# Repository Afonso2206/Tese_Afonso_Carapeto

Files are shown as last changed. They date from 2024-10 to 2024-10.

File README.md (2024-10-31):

This repository contains the source code, schematic, and PCB layout for the electronic badge developed as part of the thesis project of Afonso Carapeto. 

Getting Started: Reprogramming the E-Badge:

- Install the Arduino IDE: If you haven't already, download and install the Arduino IDE, which is available at https://www.arduino.cc/en/software.

Add Raspberry Pi Pico Support: In the Arduino IDE, you’ll need to add support for the Raspberry Pi Pico board (the microcontroller used in this badge). Follow these steps:
- Open the Arduino IDE and go to File > Preferences.
- In the "Additional Boards Manager URLs" field, add the following URL: https://github.com/earlephilhower/arduino-pico/releases/download/global/package_rp2040_index.json

Install the Raspberry Pi Pico Package:

- Go to Tools > Board > Boards Manager.
- Search for "Raspberry Pi Pico" in the Boards Manager.
- Install the package named Raspberry Pi Pico/RP2040 by Earle Philhower.

Select the Board and Port:

- Connect your badge (Raspberry Pi Pico) to your computer via USB.
- In the Arduino IDE, go to Tools > Board and select Raspberry Pi Pico.
- Then, under Tools > Port, select the port that corresponds to your badge.

  Upload Code to the Badge: Now you can open any of the .ino files in this repository, modify the code if desired, and click Upload to program the badge.

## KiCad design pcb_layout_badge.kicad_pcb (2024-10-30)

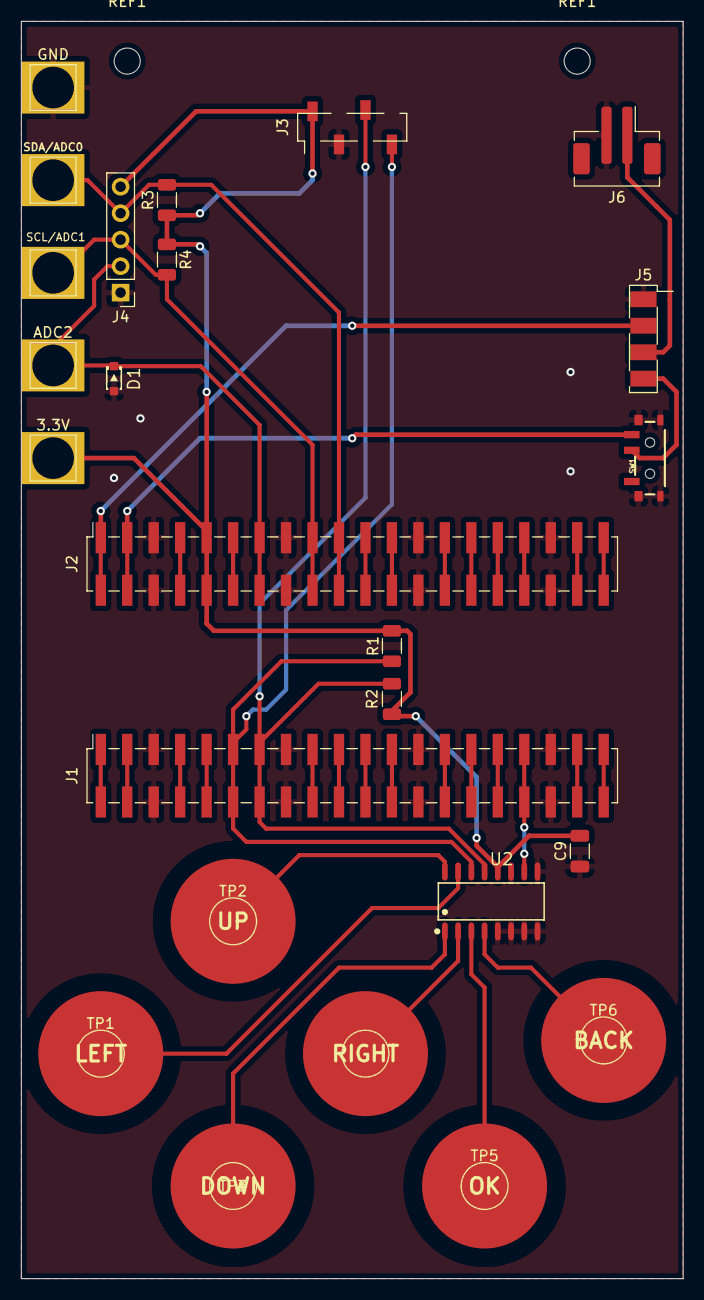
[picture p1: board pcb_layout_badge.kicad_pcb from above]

Board: 2 copper layers, 63.5 x 120.7 mm, 28 parts (1 on the bottom side), 41 nets.

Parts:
3.3V: TestPoint; TestPoint_THTPad_4.0x4.0mm_Drill2.0mm
ADC2: TestPoint; TestPoint_THTPad_4.0x4.0mm_Drill2.0mm
C9: 0.1u; C_1206_3216Metric
D1: D_Zener; zener
G1: LOGO
GND: TestPoint; TestPoint_THTPad_4.0x4.0mm_Drill2.0mm
J1, J2: Conn_01x40_Female; PinSocket_2x20_P2.54mm_Vertical_SMD
J3: Conn_01x04_Female; PinSocket_1x04_P2.54mm_Vertical_SMD_Pin1Left
J4: Conn_01x05_Male; PinHeader_1x05_P2.54mm_Vertical
J5: Conn_01x04_Male; carregador_v2
J6: Conn_01x02_Male; JST_PH_B2B-PH-SM4-TB_1x02-1MP_P2.00mm_Vertical
R1, R2, R3, R4: 4.7k; R_1206_3216Metric
REF1, REF1#2: MountingHole_2.5mm
SCL/ADC1: TestPoint; TestPoint_THTPad_4.0x4.0mm_Drill2.0mm
SDA/ADC0: TestPoint; TestPoint_THTPad_4.0x4.0mm_Drill2.0mm
SW1: SW_SPST; SWITCH_SPST_SMD_A
TP1, TP2, TP3, TP4, TP5, TP6: TestPoint; TestPoint_Pad_D4.0mm
U2: cap_sensor; SOP-16_L10.0-W3.9-P1.27-LS6.0-BL

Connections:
+3.3V: 3.3V.1, C9.2, J2.9, J2.10, J3.1, J4.5, R1.2, R2.2, R3.1, R4.1, U2.12 (VDD)
ADC0/SDA1: J2.19, J2.20, J4.4, R3.2, SDA/ADC0.1
ADC1/SCL1: J2.17, J2.18, J4.3, R4.2, SCL/ADC1.1
ADC2: ADC2.1, D1.1 (K), J2.13, J2.14, J4.2
GND: C9.1, D1.2 (A), GND.1, J1.5, J1.6, J1.15, J1.16, J1.25, J1.26, J1.35, J1.36, J2.5, J2.6, J2.15, J2.16, J2.25, J2.26, J2.35, J2.36, J3.2, J4.1, J5.1, J6.2, SW1.GND1, SW1.GND2, SW1.GND3, SW1.GND4, U2.5 (Key7), U2.6 (Key8), U2.7 (Key9), U2.8 (Key10), U2.9 (Key11), U2.11 (VSS)
unnamed: J1.1, J1.2
unnamed: J1.3, J1.4
unnamed: J1.7, J1.8
unnamed: J1.9, J1.10
unnamed: J1.17, J1.18
unnamed: J1.19, J1.20
unnamed: J1.21, J1.22
unnamed: J1.23, J1.24
unnamed: J1.27, J1.28
unnamed: J1.29, J1.30
unnamed: J1.31, J1.32
unnamed: J1.33, J1.34, U2.10 (Key12/IRQ)
unnamed: J1.37, J1.38
unnamed: J1.39, J1.40
unnamed: J2.7, J2.8
unnamed: J2.11, J2.12
unnamed: J2.21, J2.22
unnamed: J2.23, J2.24
unnamed: J2.27, J2.28
unnamed: J2.29, J2.30
unnamed: J2.31, J2.32
unnamed: J2.33, J2.34
unnamed: J2.37, J2.38
unnamed: J2.39, J2.40
unnamed: J5.4, SW1.2 (B)
unnamed: TP1.1, U2.15 (KEY1)
unnamed: TP2.1, U2.16 (KEY2)
unnamed: TP3.1, U2.1 (KEY3)
unnamed: TP4.1, U2.2 (Key4)
unnamed: TP5.1, U2.3 (Key5)
unnamed: TP6.1, U2.4 (Key6)
SCL0: J1.13, J1.14, J3.3, R2.1, U2.13 (SCL)
SDA0: J1.11, J1.12, J3.4, R1.1, U2.14 (SDA)
VBAT: J5.3, J6.1
VBUS: J2.1, J2.2, J5.2
VSYS: J2.3, J2.4, SW1.1 (A)

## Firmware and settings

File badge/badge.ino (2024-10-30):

#include "oled.h"

#include "snake.h"

#include "time_functions.h"

#include "treasure_hunt.h"

#include "tic_tac_toe.h"

#include <Wire.h>

#define SLAVE_ADDRESS 0x50 //   Touch Key Controller Address

GyverOLED<SSH1106_128x64> oled;

//----------------------------------------TIMEOUT VARIABLES---------------------------------//

unsigned long lastActivityTime = 0;
const unsigned long inactivityTimeout = 10000;

//--------------------------------TOUCH KEY CONTROLLER VARIABLES-----------------------------//
uint8_t KeyStatus0, i; 
uint8_t Array_SettingRegisters[22];
bool back_key_pressed = false;

//---------------------------------------SNAKE GAME VARIABLES----------------------------------------//

bool Snake_Game = false;
int xdir = 1;             //player direction
int ydir = 0;

//---------------------------------------TIC TAC TOE VARIABLES----------------------------------------//

bool tic_tac_toe_game = false;

//---------------------------------------TIC TAC TOE VARIABLES----------------------------------------//

bool treasure_hunt = false;

//--------------------------------------------------------------------------------------------------//
//--------------------------------------------------------------------------------------------------//
//--------------------------------------------------------------------------------------------------//

void ReadAndProcessKeyStatus();
void Key_Instrucion(uint8_t KeyPressed);
uint8_t Read_SettingRegisters(uint8_t Register);
void Write_SettingRegisters();

void navigate_up();
void navigate_down();
void exit_submenu();
void select_submenu_option();
void update_menu();
void select_submenu_option();

int main() {

    clock_and_rtc_initialization();    
     

    //I2c Communication Intialization
    Wire.begin();

    //OLED Intialization
    DisplayStartupSequence(); 
    oled.clear();
    update_menu();
    
    //Touch Controller Intialization
    for (i = 0xB0; i < 0xC6; i++) {
        Array_SettingRegisters[i - 0xB0] = Read_SettingRegisters(i);
    }

    Write_SettingRegisters();

    //Main Loop
    while (true) {
        unsigned long currentTime = millis();         //Checks to see if 10 seconds pass without a key being pressed
        if (KeyStatus0 != 0){
          lastActivityTime = currentTime;
        }
        if (currentTime - lastActivityTime >= inactivityTimeout){
          prepareSleep();             //If 10 seconds pass, the pico goes to sleep
        }
        delay(100); 
        ReadAndProcessKeyStatus();
    }
}

//--------------------------------------------------------------------------------------------------//
//--------------------------------------------------------------------------------------------------//
//--------------------------------------------------------------------------------------------------//

void ReadAndProcessKeyStatus() {
    Wire.beginTransmission(SLAVE_ADDRESS);
    Wire.write(0x08); // Key1-8 Status Data Register: 08H (This touch controller supports 12 keys)
    Wire.endTransmission();
    Wire.requestFrom(SLAVE_ADDRESS, 1);
    while (Wire.available()) KeyStatus0 = Wire.read();

    if (KeyStatus0 != 0) {
        //digitalWrite(LED_BUILTIN, HIGH);
        Key_Instruction(KeyStatus0);
    } else {
        //digitalWrite(LED_BUILTIN, LOW);
    }
}

void Key_Instruction(uint8_t KeyPressed) {
  oled.clear();
  oled.home();

  if(!Snake_Game && !tic_tac_toe_game && !treasure_hunt){               //Menu Navigation
    switch (KeyPressed) {
      case 0x01:
        //oled.println("LEFT");    //Presses "LEFT"
        break;
      case 0x02:                 //Presses "UP"
        navigate_up();
        break;
      case 0x04:                 //Presses "DOWN"
        navigate_down();
        break;
      case 0x08:
        //oled.println("RIGHT");   //Presses "RIGHT"
        break;
      case 0x10:                 //Presses "OK"
        if (!in_submenu) {
          in_submenu = true;
          update_menu();
        } else {
          select_submenu_option();    
        }
        break;
      case 0x20:                 //Presses "BACK"
        if (in_submenu) {
          exit_submenu();
          current_submenu_index = 0;
          back_key_pressed = true;
        }
        break;
    }
  }
  else 
  {
    if (KeyStatus0 & 0x20){   //If In Snake Game
      exit_submenu();
      back_key_pressed = true;
      oled.update();
    }
  }
  
  //oled.update();
}


uint8_t Read_SettingRegisters(uint8_t Register) {
    Wire.beginTransmission(SLAVE_ADDRESS);
    Wire.write(Register);
    Wire.endTransmission();
    Wire.requestFrom(SLAVE_ADDRESS, 1);
    while (Wire.available()) return Wire.read();
    return 0;
}

void Write_SettingRegisters() {
    Wire.beginTransmission(SLAVE_ADDRESS);
    Wire.write(0xB0);
    for (i = 0; i < 22; i++) {
        Wire.write(Array_SettingRegisters[i]);
    }
    Wire.endTransmission();
}

void navigate_up() {
  // Move selection up based on whether in main menu or submenu
  if (in_submenu) {
    // Move selection up in the submenu
    if (current_submenu_index > 0) {
      current_submenu_index--;
    } else {
      // Wrap around to the bottom of the submenu if at the top
      current_submenu_index = submenu_length - 1;
    }
  } else {
    // Move selection up in the main menu
    if (current_index > 0) {
      current_index--;
    } else {
      // Wrap around to the bottom of the menu if at the top
      current_index = menu_length - 1;
    }
  }
  update_menu();
}

void navigate_down() {
  // Move selection down based on whether in main menu or submenu
  if (in_submenu) {
    // Move selection down in the submenu
    if (current_submenu_index < submenu_length - 1) {
      current_submenu_index++;
    } else {
      // Wrap around to the bottom of the submenu if at the top
      current_submenu_index = 0;
    }
  } else {
    // Move selection down in the main menu
    if (current_index < menu_length - 1) {
      current_index++;
    } else {
      // Wrap around to the top of the menu if at the bottom
      current_index = 0;
    }
  }
  update_menu();
}

void exit_submenu() {
  // Exit the submenu and go back to the main menu
  in_submenu = false;
  update_menu();
}

void select_submenu_option() {
  const char* option = submenu_items[current_index][current_submenu_index];
  oled.clear();
  oled.home();
  oled.setScale(1);
  oled.invertText(false);
  if (option == "See student data"){
    print_student_data();                 //Show Student Data
  }
  else if (option == "Show QR Code"){
    displayQRCode(Student_Info);          //Display QR Code with Student Data
  }
  else if (option == "Snake"){
    Snake_Game = true;
    run_snake_game();
  }
  else if (option == "Tic Tac Toe"){
    tic_tac_toe_game = true;
    run_tic_tac_toe();
  }
  else if (option == "Digital"){
    delay(100);
    back_key_pressed = false;
    while(!back_key_pressed){
     digital_Voltmeter();       //Digital Voltmeter
     ReadAndProcessKeyStatus();
     delay(10);
    }
    back_key_pressed = false;
  }
  else if (option == "Analog"){
    delay(100);
    back_key_pressed = false;
    while(!back_key_pressed){     
      analog_Voltmeter();       //Analog Voltmeter
      ReadAndProcessKeyStatus();
      delay(10);
    }
    back_key_pressed = false;
  }
  else if (option == "Treasure Hunt"){    //Treasure Hunt Game
    treasure_hunt = true;
    run_treasure_hunt();
    unsigned long currentTime = millis(); 
    lastActivityTime = currentTime;
  }
  
  else if (option == "Focus Attention"){
    Focus_Preparation();                  //Prints information before starting the Focus Attention Functionality
    back_key_pressed = false;
    while(!back_key_pressed){
      Focus_Attention();                  //Fills the Focus Attention bar
      ReadAndProcessKeyStatus();
      delay(10);
    }
    percent = 0;                          //Puts the percentage of the Focus Attention bar back at zero
    back_key_pressed = false;
  }
  else if (option == "IST Alameda"){
    print_alameda_info();                 //Prints Information about the Alameda Campus
  }
  else if (option == "IST Taguspark"){
    print_taguspark_info();               //Prints Information about the Taguspark Campus
  }
  
  oled.update();
}

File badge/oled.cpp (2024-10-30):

#include "oled.h"

const char* menu_items[6] = {
    "Student Data",
    "Games",
    "Voltmeter",
    "Treasure Hunt",
    "Focus Attention",
    "IST Info"
  };

const char* submenu_items[6][3] = {
  {"See student data", "Show QR Code", nullptr},      // Submenu options for Student Data
  {"Snake", "Tic Tac Toe", nullptr},            // Submenu options for Games
  {"Digital", "Analog", nullptr},    // Submenu options for Voltmeter
  {"Treasure Hunt", nullptr},  // Submenu options for I2C Explorer
  {"Focus Attention", nullptr},  // Submenu options for Focus Attention
  {"IST Alameda", "IST Taguspark", nullptr}       // Submenu options for IST Info
};
  
const int menu_length = sizeof(menu_items) / sizeof(menu_items[0]);
int current_index = 0;
int current_submenu_index = 0;
bool in_submenu = false;
int submenu_length = 0;

const char* Student_Info = "BEGIN:VCARD\n"
                       "VERSION:3.0\n"
                       "FN;CHARSET=UTF-8:Afonso Santos Carapeto\n"
                       "N;CHARSET=UTF-8:Carapeto;Afonso;Santos;;\n"
                       "EMAIL;CHARSET=UTF-8;type=HOME,INTERNET:afonso.carapeto@tecnico.ulisboa.pt\n"
                       "TEL;TYPE=CELL:+351 929264325\n"
                       "NOTE;CHARSET=UTF-8:MEEC nº 93763\n"
                       "REV:2024-01-16T14:41:13.993Z\n"
                       "END:VCARD\n"; 

byte percent = 0;
//-------------------------------------------------------------------------------------------------------------------//

void DisplayStartupSequence() {

    const uint8_t IST_Logo[128*8] PROGMEM  = {
  0x00, 0x00, 0x00, 0x00, 0x00, 0x00, 0x00, 0x00, 0x00, 0x00, 0x00, 0x00, 0x00, 0x00, 0x00, 0x00, 
  0x00, 0x00, 0x00, 0x00, 0x00, 0x00, 0x00, 0x00, 0x00, 0x00, 0x00, 0x00, 0x00, 0x00, 0x00, 0x00, 
  0x00, 0x00, 0x00, 0x00, 0x00, 0x00, 0xff, 0xff, 0xff, 0xff, 0xff, 0xff, 0xff, 0xff, 0xff, 0xff, 
  0xff, 0xff, 0xff, 0xff, 0xff, 0xff, 0xff, 0xff, 0xff, 0xff, 0xff, 0xff, 0xff, 0xff, 0xff, 0xff, 
  0x7f, 0x3f, 0x3f, 0xbf, 0xbf, 0xbf, 0xbf, 0x3f, 0x3f, 0x3f, 0x7f, 0xff, 0xff, 0xff, 0xff, 0xff, 
  0xff, 0xff, 0xff, 0xff, 0xff, 0xff, 0xff, 0xff, 0xff, 0xff, 0x00, 0x00, 0x00, 0x00, 0x00, 0x00, 
  0x00, 0x00, 0x00, 0x00, 0x00, 0x00, 0x00, 0x00, 0x00, 0x00, 0x00, 0x00, 0x00, 0x00, 0x00, 0x00, 
  0x00, 0x00, 0x00, 0x00, 0x00, 0x00, 0x00, 0x00, 0x00, 0x00, 0x00, 0x00, 0x00, 0x00, 0x00, 0x00, 
  0x00, 0x00, 0x00, 0x00, 0x00, 0x00, 0x00, 0x00, 0x00, 0x00, 0x00, 0x00, 0x00, 0x00, 0x00, 0x00, 
  0x00, 0x00, 0x00, 0x00, 0x00, 0x00, 0x00, 0x00, 0x00, 0x00, 0x00, 0x00, 0x00, 0x00, 0x00, 0x00, 
  0x00, 0x00, 0x00, 0x00, 0x00, 0x00, 0xff, 0xff, 0xff, 0xff, 0xff, 0xff, 0xff, 0xff, 0xff, 0xff, 
  0xff, 0xff, 0xff, 0xff, 0xff, 0xff, 0xff, 0xff, 0xff, 0xff, 0xff, 0xff, 0xff, 0xff, 0x01, 0x00, 
  0x00, 0x00, 0x00, 0xff, 0xff, 0xff, 0xff, 0xf8, 0xe0, 0xe0, 0xe0, 0xe0, 0xff, 0xff, 0xff, 0xff, 
  0xff, 0xff, 0xff, 0xff, 0xff, 0xff, 0xff, 0xff, 0xff, 0xff, 0x00, 0x00, 0x00, 0x00, 0x00, 0x00, 
  0x00, 0x00, 0x00, 0x00, 0x00, 0x00, 0x00, 0x00, 0x00, 0x00, 0x00, 0x00, 0x00, 0x00, 0x00, 0x00, 
  0x00, 0x00, 0x00, 0x00, 0x00, 0x00, 0x00, 0x00, 0x00, 0x00, 0x00, 0x00, 0x00, 0x00, 0x00, 0x00, 
  0x00, 0x00, 0x00, 0x00, 0x00, 0x00, 0x00, 0x00, 0x00, 0x00, 0x00, 0x00, 0x00, 0x00, 0x00, 0x00, 
  0x00, 0x00, 0x00, 0x00, 0x00, 0x00, 0x00, 0x00, 0x00, 0x00, 0x00, 0x00, 0x00, 0x00, 0x00, 0x00, 
  0x00, 0x00, 0x00, 0x00, 0x00, 0x00, 0xff, 0xff, 0xff, 0xff, 0xff, 0xff, 0xff, 0xff, 0xff, 0xff, 
  0xff, 0xff, 0xff, 0xff, 0x01, 0x01, 0x01, 0x01, 0x01, 0xff, 0xff, 0xff, 0xff, 0xff, 0x00, 0x00, 
  0x00, 0x00, 0x00, 0xff, 0xff, 0xf1, 0xf1, 0x01, 0x01, 0x01, 0x01, 0x01, 0xf1, 0xf1, 0xf1, 0xff, 
  0xff, 0xff, 0xff, 0xff, 0xff, 0xff, 0xff, 0xff, 0xff, 0xff, 0x00, 0x00, 0x00, 0x00, 0x00, 0x00, 
  0x00, 0x00, 0x00, 0x00, 0x00, 0x00, 0x00, 0x00, 0x00, 0x00, 0x00, 0x00, 0x00, 0x00, 0x00, 0x00, 
  0x00, 0x00, 0x00, 0x00, 0x00, 0x00, 0x00, 0x00, 0x00, 0x00, 0x00, 0x00, 0x00, 0x00, 0x00, 0x00, 
  0x00, 0x00, 0x00, 0x00, 0x00, 0x00, 0x00, 0x00, 0x00, 0x00, 0x00, 0x00, 0x00, 0x00, 0x00, 0x00, 
  0x00, 0x00, 0x00, 0x00, 0x00, 0x00, 0x00, 0x00, 0x00, 0x00, 0x00, 0x00, 0x00, 0x00, 0x00, 0x00, 
  0x00, 0x00, 0x00, 0x00, 0x00, 0x00, 0xff, 0xff, 0xff, 0xff, 0xff, 0xff, 0xff, 0xff, 0xff, 0xff, 
  0xff, 0xff, 0xff, 0xff, 0x00, 0x00, 0x00, 0x00, 0x00, 0xff, 0xff, 0xff, 0xff, 0xff, 0x00, 0x00, 
  0x00, 0x00, 0x00, 0xff, 0xff, 0xff, 0xff, 0x00, 0x00, 0x00, 0x00, 0x00, 0xff, 0xff, 0xff, 0xff, 
  0xff, 0xff, 0xff, 0xff, 0xff, 0xff, 0xff, 0xff, 0xff, 0xff, 0x00, 0x00, 0x00, 0x00, 0x00, 0x00, 
  0x00, 0x00, 0x00, 0x00, 0x00, 0x00, 0x00, 0x00, 0x00, 0x00, 0x00, 0x00, 0x00, 0x00, 0x00, 0x00, 
  0x00, 0x00, 0x00, 0x00, 0x00, 0x00, 0x00, 0x00, 0x00, 0x00, 0x00, 0x00, 0x00, 0x00, 0x00, 0x00, 
  0x00, 0x00, 0x00, 0x00, 0x00, 0x00, 0x00, 0x00, 0x00, 0x00, 0x00, 0x00, 0x00, 0x00, 0x00, 0x00, 
  0x00, 0x00, 0x00, 0x00, 0x00, 0x00, 0x00, 0x00, 0x00, 0x00, 0x00, 0x00, 0x00, 0x00, 0x00, 0x00, 
  0x00, 0x00, 0x00, 0x00, 0x00, 0x00, 0x00, 0x0f, 0x7f, 0xff, 0xff, 0xff, 0xff, 0xff, 0xff, 0xff, 
  0xff, 0xff, 0xff, 0xff, 0xe0, 0xe0, 0xe0, 0xe0, 0xe0, 0xff, 0xff, 0xff, 0xff, 0xff, 0x00, 0x00, 
  0x00, 0x00, 0x00, 0xff, 0xff, 0xff, 0xff, 0xe0, 0xe0, 0xe0, 0xe0, 0xe0, 0xff, 0xff, 0xff, 0xff, 
  0xff, 0xff, 0xff, 0xff, 0xff, 0xff, 0xff, 0xff, 0x7f, 0x0f, 0x00, 0x00, 0x00, 0x00, 0x00, 0x00, 
  0x00, 0x00, 0x00, 0x00, 0x00, 0x00, 0x00, 0x00, 0x00, 0x00, 0x00, 0x00, 0x00, 0x00, 0x00, 0x00, 
  0x00, 0x00, 0x00, 0x00, 0x00, 0x00, 0x00, 0x00, 0x00, 0x00, 0x00, 0x00, 0x00, 0x00, 0x00, 0x00, 
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
  };

    //Initializes OLED and Displays IST Logo 
    oled.init();        
    oled.clear();
    oled.drawBitmap(0, 0, IST_Logo, 128, 64);
    oled.update();
    delay(2000); 
}

//---------------------------------------------------------------------------------------------------//
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
